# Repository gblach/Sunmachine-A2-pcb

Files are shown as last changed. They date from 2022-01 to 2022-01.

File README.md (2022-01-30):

# Sunmachine-A2-pcb
The driver for WS2812, SK6812 or similar LED strips controlled via Bluetooth LE. It supports both RGB and WWA LEDs.
This driver uses motion and light sensors, so in automatic mode it can turn on the light when it detects someone's presence in the dark.
The PCB is designed for the [Hammond 1551V3](https://www.hammfg.com/electronics/small-case/plastic/1551v) enclosure, so it can be hung on a wall or ceiling.
The firmware for the board is available in [Sunmachine-A2-fw](https://github.com/gblach/Sunmachine-A2-fw) repo
and the mobile app to control the board is available in [Sunmachine-app](https://github.com/gblach/Sunmachine-app) repo.

## Key components
- [Minew MS50SFA2](https://www.minew.com/product/nrf52832-ms50sfa2/) module with Nordic nRF52832 processor.
- RCWL-0516 microwave motion sensor.
- 5626 photodiode (5526 should work too).
- SN74LV1T34DBV level shifter.
- LM1117-3.3 voltage regulator.

## Connectors
- 2-pin ARK connector - for a power supply (5V).
- 3-pin ARK connector - for a LED strip (max. 6A).
- Tag-Connect 2050 - for a programmer.

## Production files
- [Gerber file](Sunmachine-A2.zip)
- [Bill of materials](Sunmachine-A2.csv)

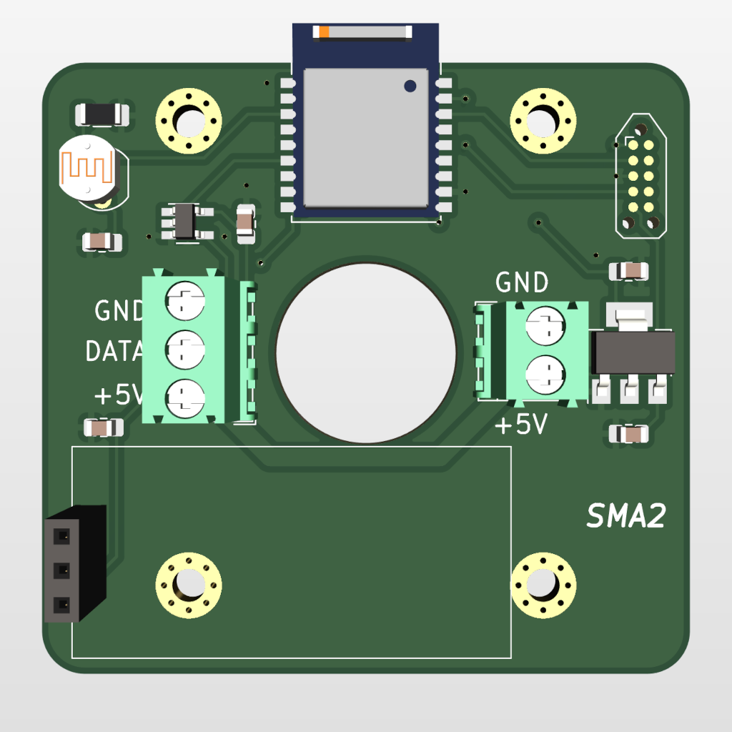
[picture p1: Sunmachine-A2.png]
PCB board


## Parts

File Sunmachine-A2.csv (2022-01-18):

Source: | /var/home/magik/collab/KiCad/Sunmachine-A2/Sunmachine-A2.kicad_sch
Date: | Mon 17 Jan 2022 11:48:58 PM
Tool: | Eeschema 6.0.1
Generator: | /app/share/kicad/plugins/bom_csv_grouped_by_value_with_fp.py
Component Count: | 14
Ref | Qnty | Value | Cmp name | Footprint | Description | Vendor
C1, C2, C3, C4, C5, | 5 | 10uF | C_Small | Capacitor_SMD:C_0805_2012Metric_Pad1.18x1.45mm_HandSolder | Unpolarized capacitor, small symbol
IC1, | 1 | RCWL-0516 | RCWL-0516 | RCWL-0516:RCWL-0516-3
J1, | 1 | Conn_02x05_Counter_Clockwise | Conn_02x05_Counter_Clockwise | Connector:Tag-Connect_TC2050-IDC-NL_2x05_P1.27mm_Vertical_with_bottom_clip | Generic connector, double row, 02x05, counter clockwise pin numbering scheme (similar to DIP packge numbering), script generated (kicad-library-utils/schlib/autogen/connector/)
J2, | 1 | Conn_01x02 | Conn_01x02 | TerminalBlock_4Ucon:TerminalBlock_4Ucon_1x02_P3.50mm_Horizontal | Generic connector, single row, 01x02, script generated (kicad-library-utils/schlib/autogen/connector/)
J3, | 1 | Conn_01x03 | Conn_01x03 | TerminalBlock_4Ucon:TerminalBlock_4Ucon_1x03_P3.50mm_Horizontal | Generic connector, single row, 01x03, script generated (kicad-library-utils/schlib/autogen/connector/)
R1, | 1 | 5626 | R_Photo | OptoDevice:R_LDR_5.1x4.3mm_P3.4mm_Vertical | Photoresistor
R2, | 1 | 10k | R | Resistor_SMD:R_1206_3216Metric_Pad1.30x1.75mm_HandSolder | Resistor
U1, | 1 | MS50SFA2 | MS50SFA2 | MS50SFA2:MS50SFA2
U2, | 1 | LM1117-3.3 | LM1117-3.3 | Package_TO_SOT_SMD:SOT-223-3_TabPin2 | 800mA Low-Dropout Linear Regulator, 3.3V fixed output, TO-220/TO-252/TO-263/SOT-223
U3, | 1 | SN74LV1T34DBV | SN74LV1T34DBV | Package_TO_SOT_SMD:SOT-23-5_HandSoldering | Single Power Supply, Single Buffer GATE, CMOS Logic, Level Shifter, SOT-23-5

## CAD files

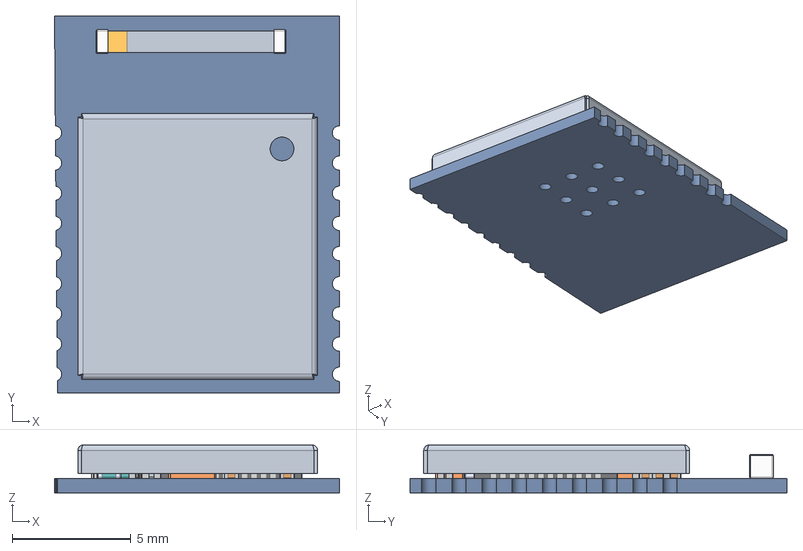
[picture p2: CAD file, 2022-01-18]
MS50SFA2.models/MS50SFA2.step
12.0 x 15.9 x 2.02 mm
Board
ms50sfa
ant8010
N52832-QFN x 2
epson2016
2012crystal

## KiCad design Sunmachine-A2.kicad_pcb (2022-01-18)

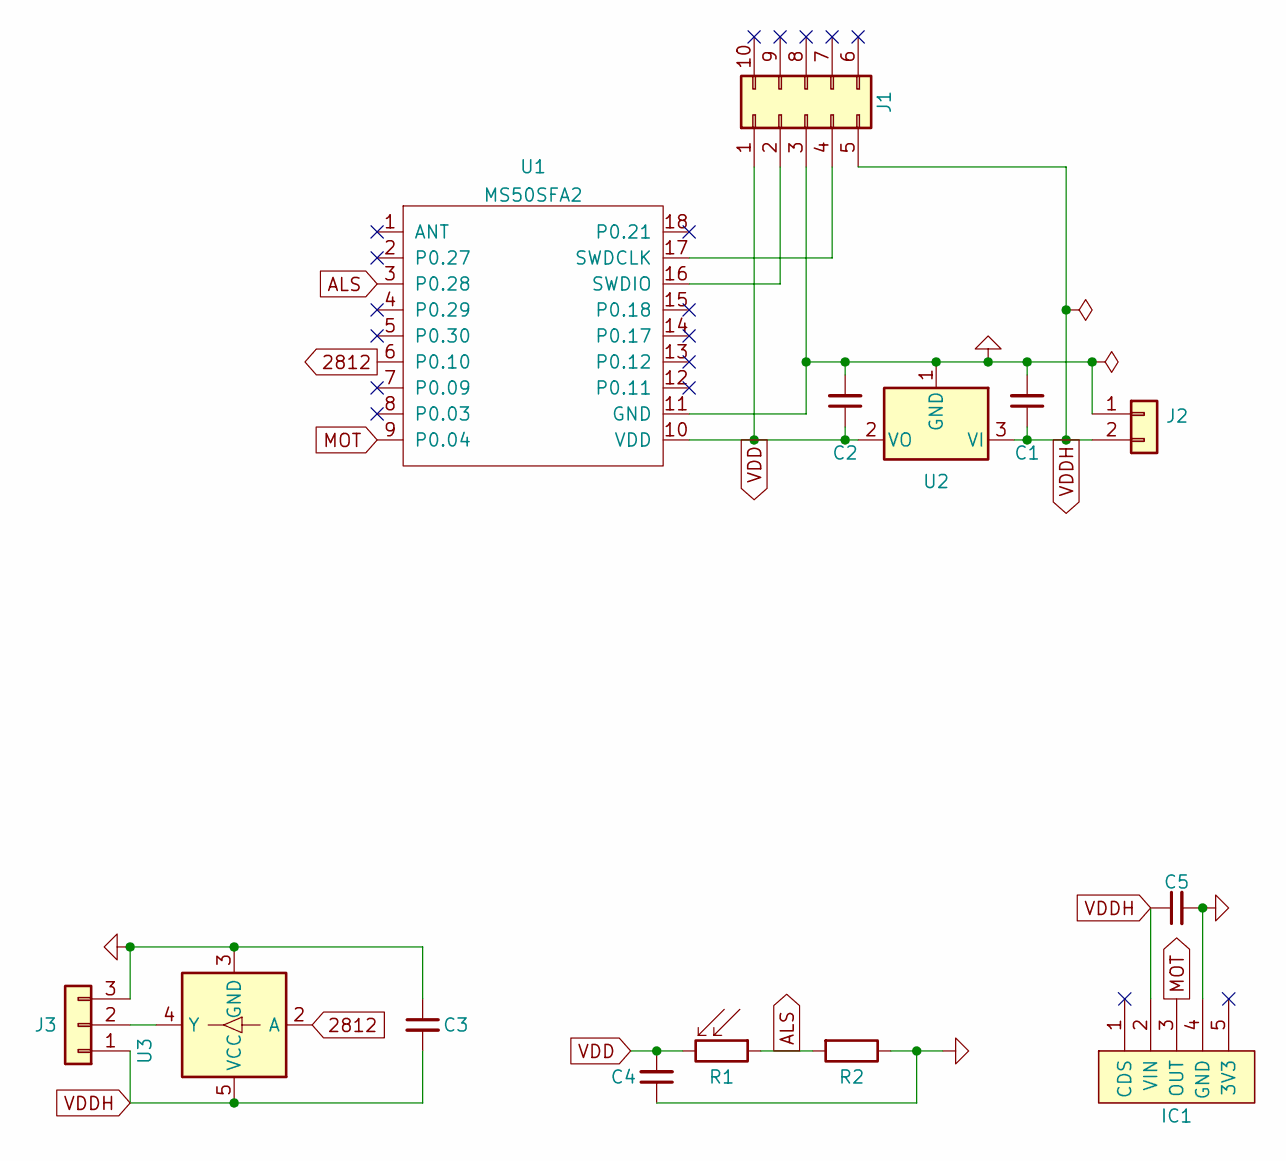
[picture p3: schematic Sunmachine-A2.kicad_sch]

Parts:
C1, C2, C3, C4, C5: 10uF; C_0805_2012Metric_Pad1.18x1.45mm_HandSolder; LCSC C15850
IC1: RCWL-0516; RCWL-0516-3
J1: Conn_02x05_Counter_Clockwise; Tag-Connect_TC2050-IDC-NL_2x05_P1.27mm_Vertical_with_bottom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
J2: Conn_01x02; TerminalBlock_4Ucon_1x02_P3.50mm_Horizontal
J3: Conn_01x03; TerminalBlock_4Ucon_1x03_P3.50mm_Horizontal
R1: 5626; R_LDR_5.1x4.3mm_P3.4mm_Vertical
R2: 10k; R_1206_3216Metric_Pad1.30x1.75mm_HandSolder; LCSC C17902
U1: MS50SFA2
U2: LM1117-3.3; SOT-223-3_TabPin2; LCSC C6186
U3: SN74LV1T34DBV; SOT-23-5_HandSoldering; LCSC C100024

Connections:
2812: U1.6 (P0.10), U3.2 (A)
ALS: R1.1, R2.2, U1.3 (P0.28)
GND: C1.2, C2.2, C3.1, C4.1, C5.2, IC1.4 (GND), J1.3, J2.1, J3.3, R2.1, U1.11 (GND), U2.1 (GND), U3.3 (GND)
MOT: IC1.3 (OUT), U1.9 (P0.04)
unnamed: J1.2, U1.16 (SWDIO)
unnamed: J1.4, U1.17 (SWDCLK)
unnamed: J3.2, U3.4 (Y)
VDD: C2.1, C4.2, J1.1, R1.2, U1.10 (VDD), U2.2 (VO)
VDDH: C1.1, C3.2, C5.1, IC1.2 (VIN), J1.5, J2.2, J3.1, U2.3 (VI), U3.5 (VCC)

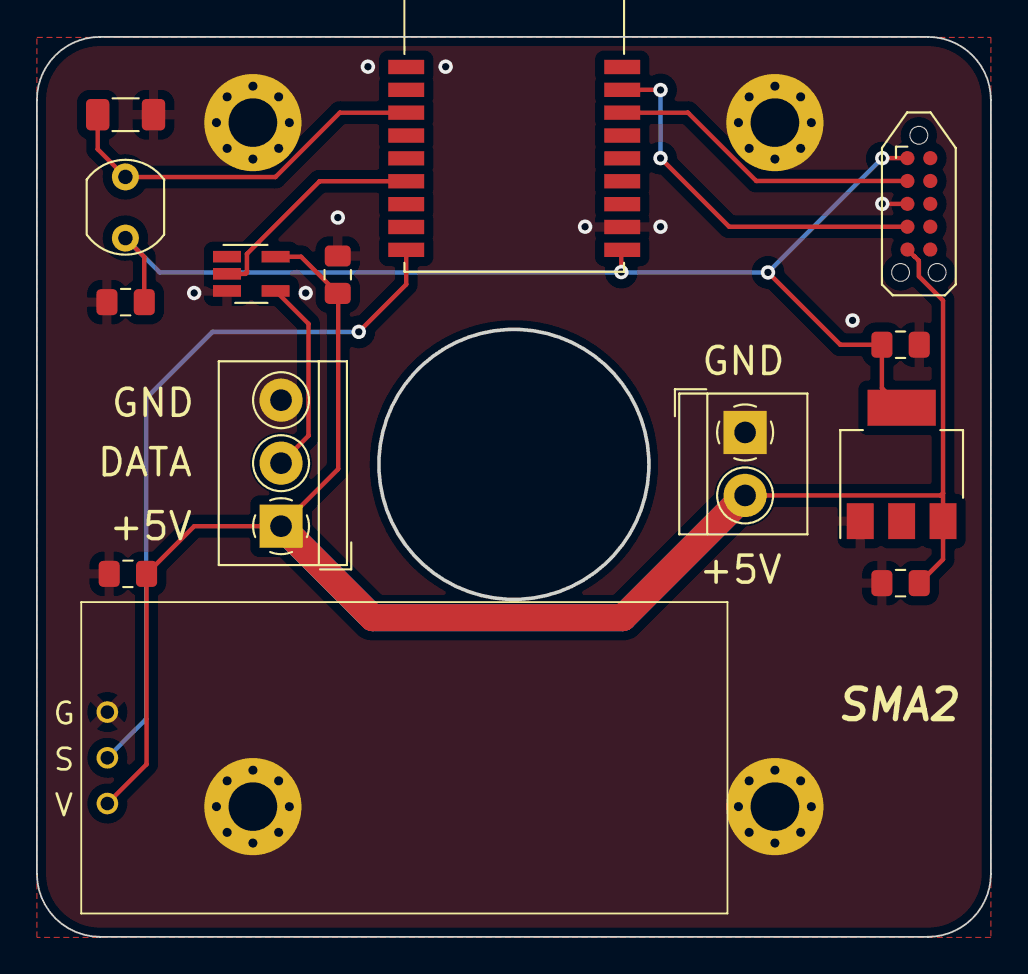
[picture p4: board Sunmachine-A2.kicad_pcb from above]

Board: 2 copper layers, 53.0 x 50.0 mm, 14 parts (0 on the bottom side), 9 nets.
